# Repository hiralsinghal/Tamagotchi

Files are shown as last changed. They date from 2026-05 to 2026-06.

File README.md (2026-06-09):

# Tamagotchi

This is a Tamagotchi. It is a small handheld video game in which you have a pet. You can play with it, feed it and more depending on your firmware code.

## Features

- Play with the pet!
- Feed it!
- Make it sleep!

You can always customise the firmware to make it do what you want!

## Schematic

Here's the schematic for the Tamagotchi. It has XIAO-ESP32-C3-SMD as its MCU. It has an OLED display, a buzzer, 4 switches and a battery cell.

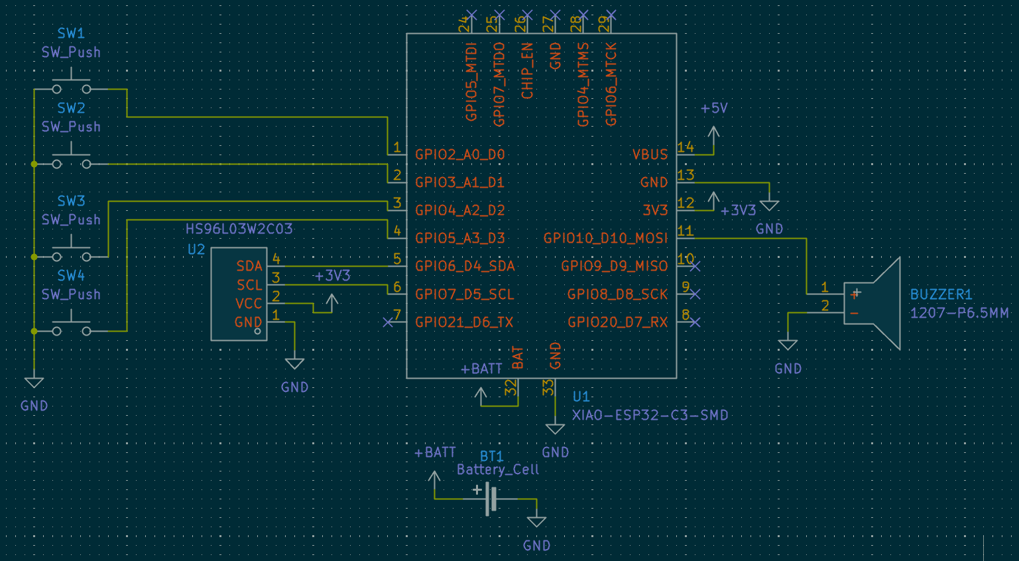
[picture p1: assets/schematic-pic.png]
Schematic


## PCB

Its a pentagon shaped PCB, which has stars on it silkscreen.

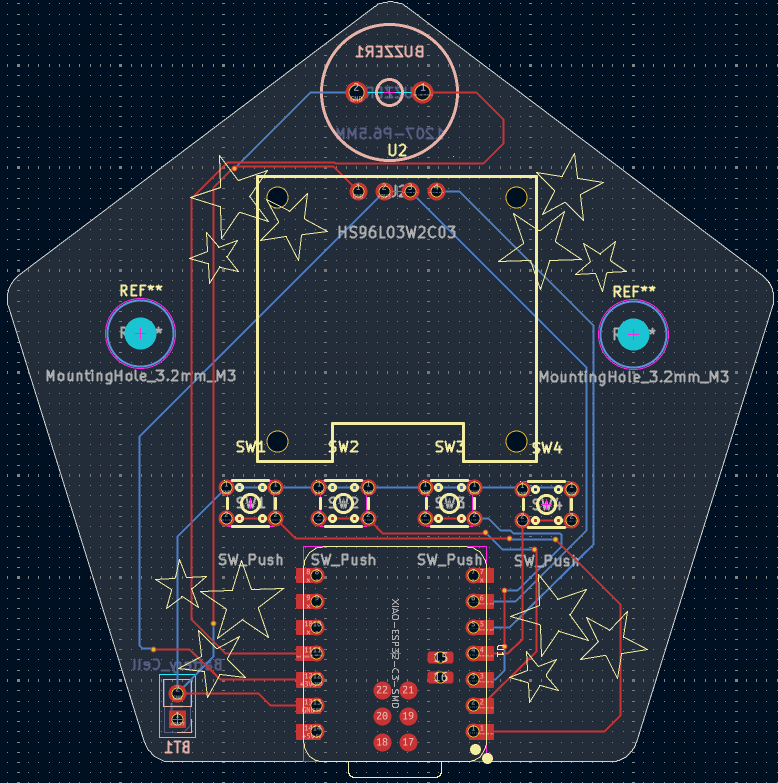
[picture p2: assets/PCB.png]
PCB


## Case

I made the case using Fusion. It has stars on the top case (goes with the PCB).

The source file is in the folder CAD.

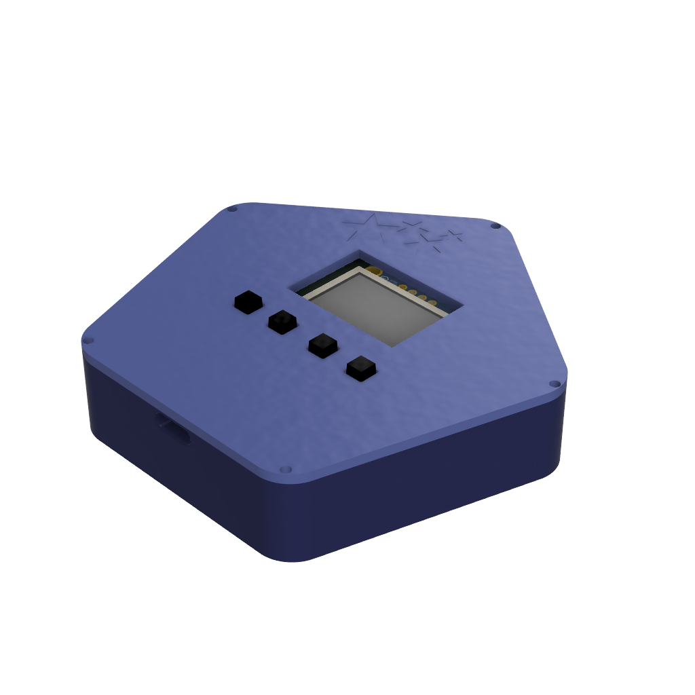
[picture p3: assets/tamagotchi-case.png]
Tamagotchi Case


## BOM

Here you can find the [BOM](BOM.csv)!

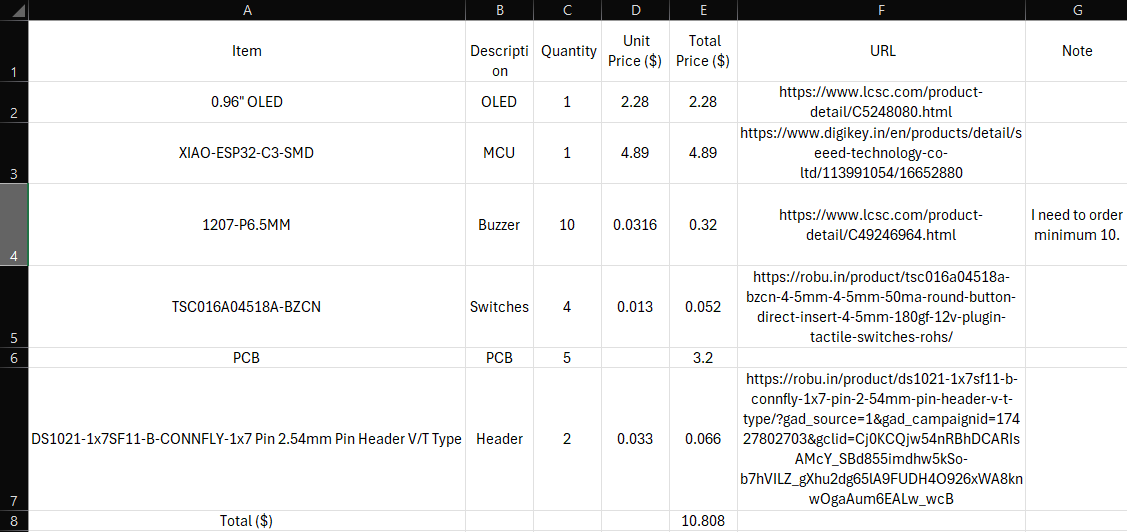
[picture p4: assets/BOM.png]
BOM


## Zine

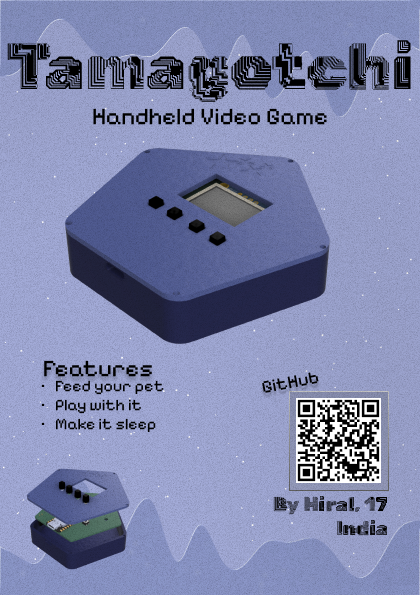
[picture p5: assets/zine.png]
Zine


## Why did I make it?

I made it for Fallout. Making this improved my electronics skills. I now know that I should read datasheets to understand how a pin on a component works. Because of this, I had to work on CAD which are now a lot better than before.

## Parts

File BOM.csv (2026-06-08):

Item | Description | Quantity | Unit Price ($) | Total Price ($) | URL | Note
0.96" OLED | OLED | 1 | 2.28 | 2.28 | https://www.lcsc.com/product-detail/C5248080.html
XIAO-ESP32-C3-SMD | MCU | 1 | 4.89 | 4.89 | https://www.digikey.in/en/products/detail/seeed-technology-co-ltd/113991054/16652880
1207-P6.5MM | Buzzer | 10 | 0.0316 | 0.32 | https://www.lcsc.com/product-detail/C49246964.html | I need to order minimum 10.
TSC016A04518A-BZCN | Switches | 4 | 0.013 | 0.052 | https://robu.in/product/tsc016a04518a-bzcn-4-5mm-4-5mm-50ma-round-button-direct-insert-4-5mm-180gf-12v-plugin-tactile-switches-rohs/
PCB | PCB | 5 |  | 3.2
DS1021-1x7SF11-B-CONNFLY-1x7 Pin 2.54mm Pin Header V/T Type | Header | 2 | 0.033 | 0.066 | https://robu.in/product/ds1021-1x7sf11-b-connfly-1x7-pin-2-54mm-pin-header-v-t-type/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
Total ($) |  |  |  | 10.808

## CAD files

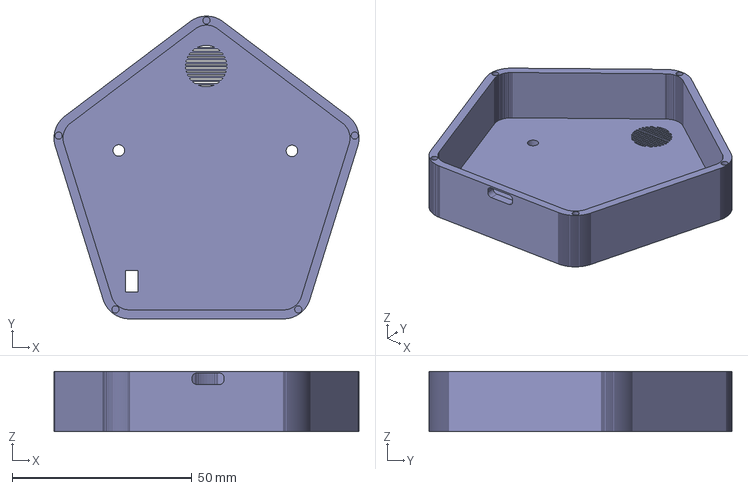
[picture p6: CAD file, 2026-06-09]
CAD/tamagotchi-bottom-case.step
84.8 x 84.1 x 16.8 mm

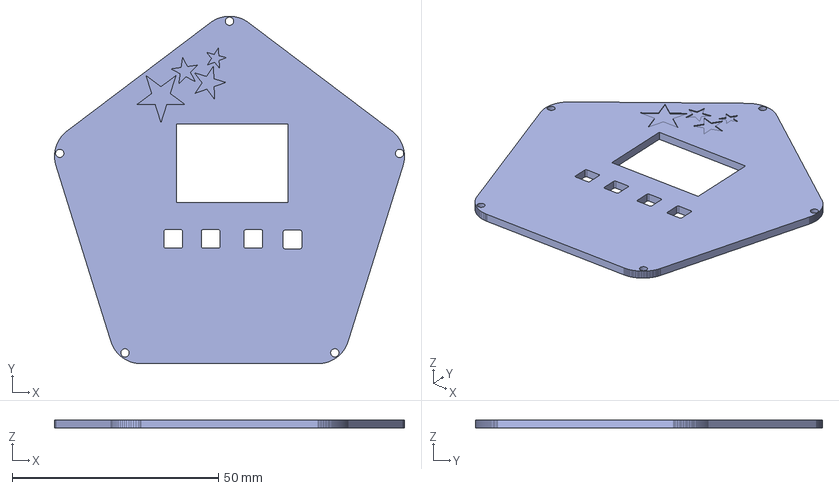
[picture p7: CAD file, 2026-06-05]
CAD/tamagotchi-top-case.step
84.8 x 84.1 x 2.00 mm

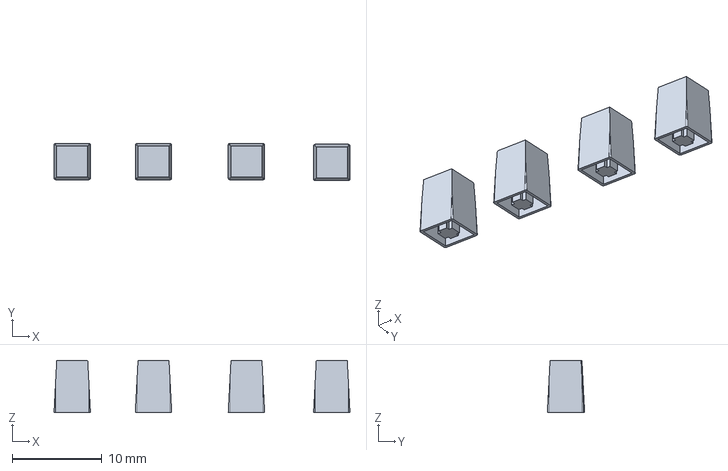
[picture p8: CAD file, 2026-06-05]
Production/tamagotchi-keycaps.step
33.0 x 4.16 x 5.80 mm

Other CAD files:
CAD/tamagotchi-case.f3z

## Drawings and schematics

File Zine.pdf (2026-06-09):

# aai

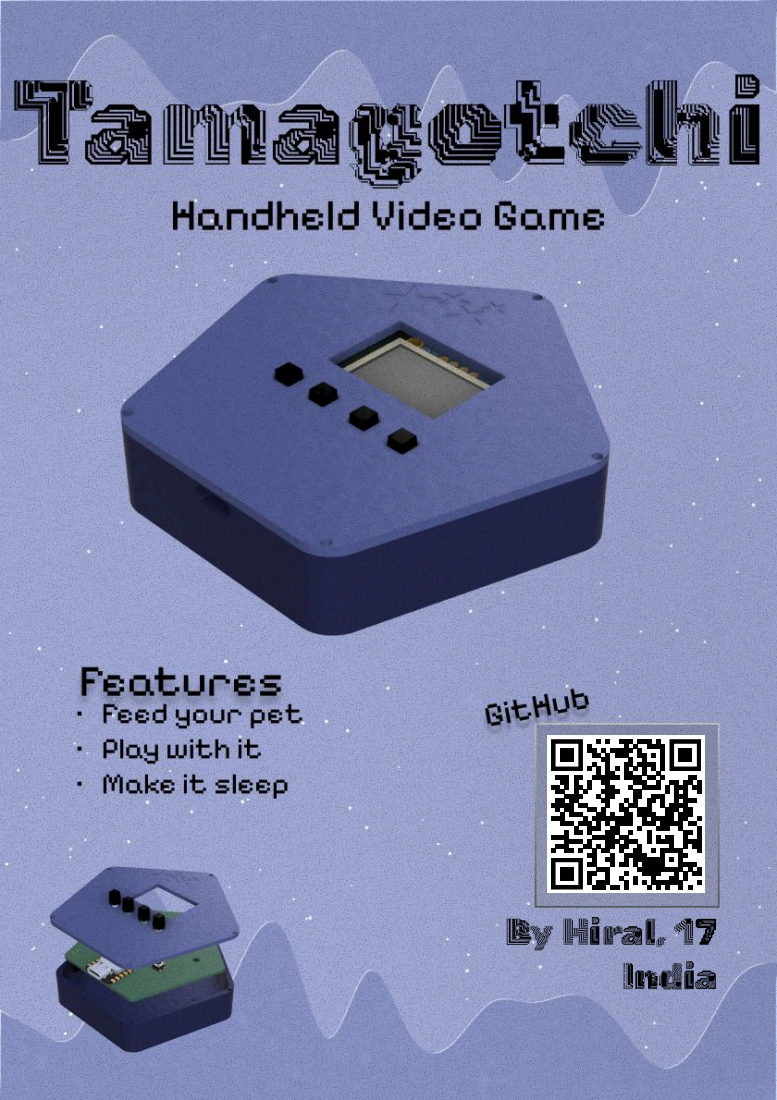
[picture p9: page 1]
By Hiral, 17 India

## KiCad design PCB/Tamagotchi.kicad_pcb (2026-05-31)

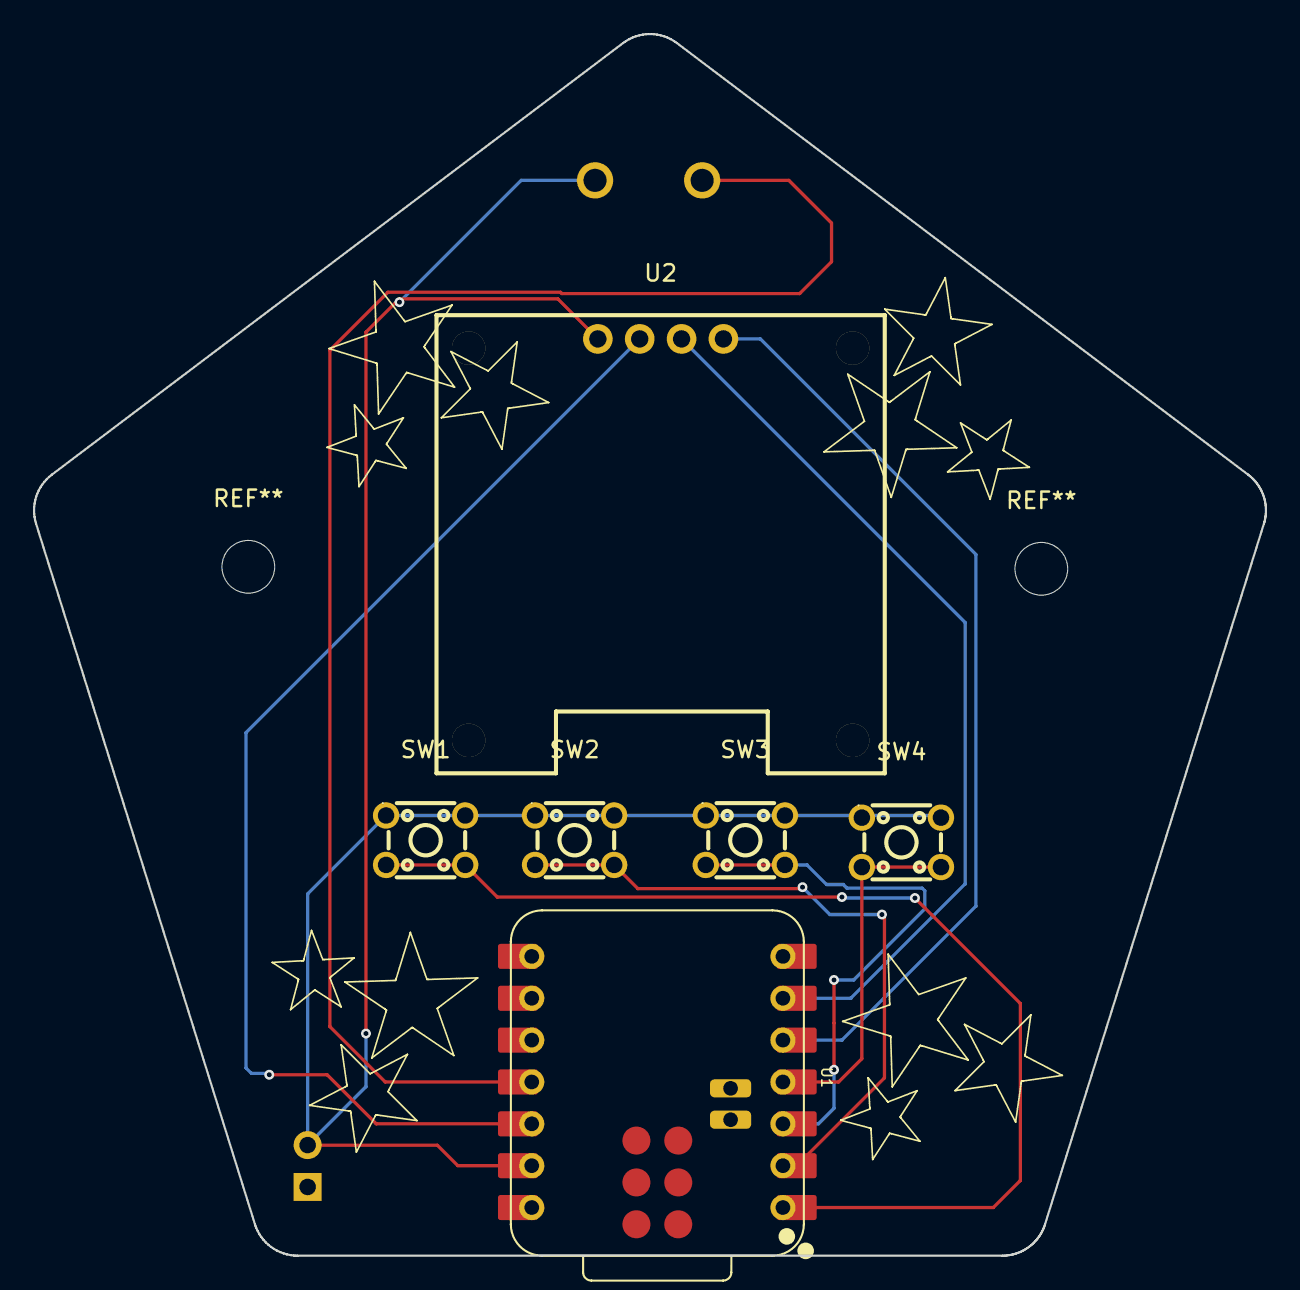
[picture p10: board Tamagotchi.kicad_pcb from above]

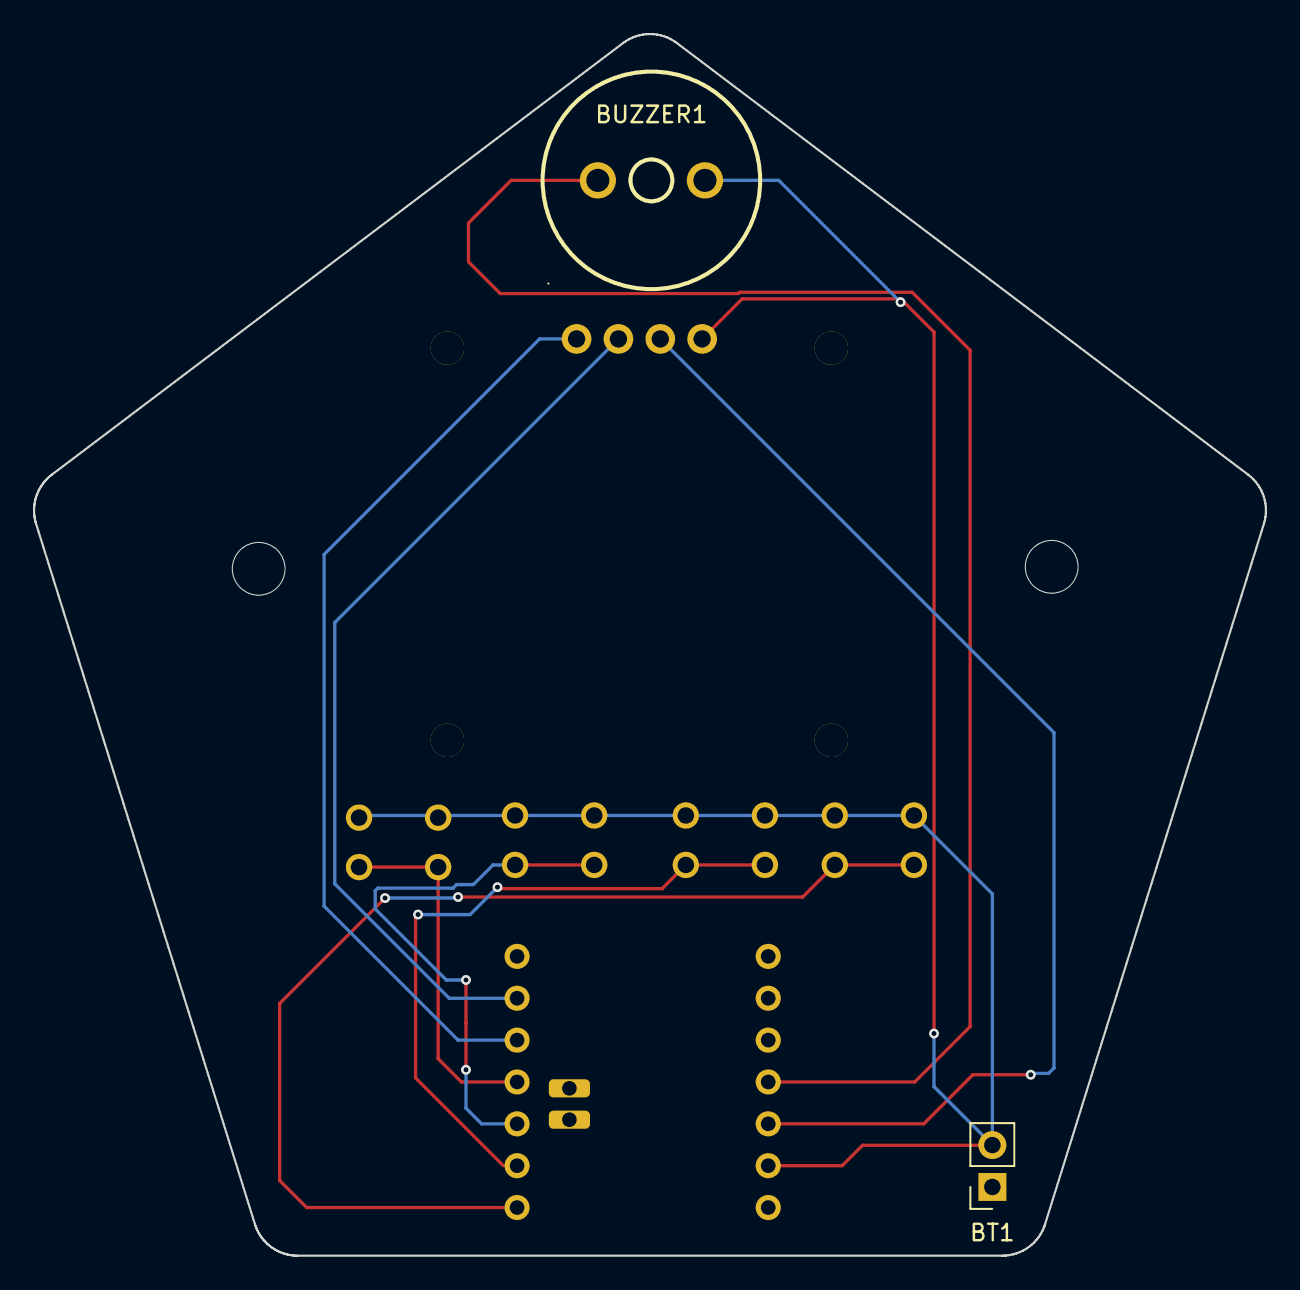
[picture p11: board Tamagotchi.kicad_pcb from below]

Board: 2 copper layers, 74.8 x 74.1 mm, 8 parts (2 on the bottom side), 9 nets.

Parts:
BT1: Battery_Cell; PinSocket_1x02_P2.54mm_Vertical
BUZZER1: 1207-P6.5MM; BUZ-TH_BD12.5-P6.50-D1.4
SW1, SW2, SW3, SW4: SW_Push; SW-TH_4P-L4.5-W4.5-P3.00-LS4.8
U1: XIAO-ESP32-C3-SMD; XIAO-ESP32-C3-DIP-SMD
U2: HS96L03W2C03; OLED-TH_L27.8-W27.2-P2.54_C9900033791

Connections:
+3V3: U1.12 (3V3), U2.2 (VCC)
GND: BT1.2 (-), BUZZER1.2 (-), SW1.1, SW2.1, SW3.1, SW4.1, U1.13 (GND), U2.1 (GND)
unnamed: BUZZER1.1 (+), U1.11 (GPIO10_D10_MOSI)
unnamed: SW1.2, U1.1 (GPIO2_A0_D0)
unnamed: SW2.2, U1.2 (GPIO3_A1_D1)
unnamed: SW3.2, U1.3 (GPIO4_A2_D2)
unnamed: SW4.2, U1.4 (GPIO5_A3_D3)
unnamed: U1.5 (GPIO6_D4_SDA), U2.4 (SDA)
unnamed: U1.6 (GPIO7_D5_SCL), U2.3 (SCL)

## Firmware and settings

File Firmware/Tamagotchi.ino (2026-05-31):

#include <Wire.h>
#include <Adafruit_GFX.h>
#include <Adafruit_SSD1306.h>

#define SCREEN_WIDTH 128
#define SCREEN_HEIGHT 64
#define OLED_RESET -1

Adafruit_SSD1306 display(SCREEN_WIDTH, SCREEN_HEIGHT, & Wire, OLED_RESET);

#define BTN1 2
#define BTN2 3
#define BTN3 4
#define BTN4 5

#define BTN_LEFT D0
#define BTN_MIDDLE_LEFT D1
#define BTN_MIDDLE_RIGHT D2
#define BTN_RIGHT D3

#define SDA_PIN 6
#define SCL_PIN 7

#define BUZZER 10

#define BUZZER_PIN D10

struct Pet {
  int hunger;
  int happiness;
  int energy;
  unsigned long age;
};

Pet pet;

enum Screen {
  SCREEN_MAIN,
  SCREEN_FEED,
  SCREEN_PLAY,
  SCREEN_SLEEP
};

Screen currentScreen = SCREEN_MAIN;

void handleScreenLogic() {
  switch(currentScreen) {

    case SCREEN_FEED:
      pet.hunger += 10;
      if(pet.hunger > 100) pet.hunger = 100;
      currentScreen = SCREEN_MAIN;
      break;

    case SCREEN_PLAY:
      pet.happiness += 10;
      pet.energy -= 5;
      if (pet.happiness > 100) pet.happiness = 100;
      if (pet.energy < 0) pet.energy = 0;
      currentScreen = SCREEN_MAIN;
      break;
    
    case SCREEN_SLEEP:
      pet.energy += 15;
      if (pet.energy > 100) pet.energy = 100;
      currentScreen = SCREEN_MAIN;
      break;

    case SCREEN_MAIN:
      break;
  }
}

unsigned long lastUpdate = 0;

void updatePet() {
  if (millis() - lastUpdate > 5000) {
    pet.hunger--;
    pet.happiness--;
    pet.energy--;

    if (pet.hunger < 0) pet.hunger = 0;
    if (pet.happiness < 0) pet.happiness =0;
    if (pet.energy < 0) pet.energy = 0;

    pet.age += 5;
    lastUpdate = millis();
  }
}

unsigned long lastButtonPress = 0;

void checkButtons() {
  if (millis() - lastButtonPress < 200) return;

  if (digitalRead(BTN_LEFT) == LOW) {
    currentScreen = SCREEN_FEED;
    tone(BUZZER_PIN, 1000, 50);
    lastButtonPress = millis();
  }

  else if (digitalRead(BTN_RIGHT) == LOW) {
    currentScreen = SCREEN_SLEEP;
    tone(BUZZER_PIN, 800, 50);
    lastButtonPress = millis();
  }
}

// Happy Face 
const unsigned char PROGMEM petHappy[] = {
  0b00000000, 0b00000000,
  0b00001111, 0b11111000,
  0b00001100, 0b00011000,
  0b00001000, 0b00001000,
  0b00001011, 0b01101000,
  0b00001000, 0b00001000,
  0b00001010, 0b00101000,
  0b00001011, 0b11101000,
  0b00001000, 0b00001000,
  0b00001111, 0b11111000,
  0b00000010, 0b00100000,
  0b00001110, 0b00111000,
  0b00001000, 0b00001000,
  0b00001000, 0b00001000,
  0b00001000, 0b00001000,
  0b00001000, 0b00001000
};

// Sad Face
const unsigned char PROGMEM petSad[] = {
  0b00000000, 0b00000000,
  0b00001111, 0b11111000,
  0b00001100, 0b00011000,
  0b00001000, 0b00001000,
  0b00001011, 0b01101000,
  0b00001000, 0b00001000,
  0b00001011, 0b11101000,
  0b00001010, 0b00101000,
  0b00001000, 0b00001000,
  0b00001111, 0b11111000,
  0b00000010, 0b00100000,
  0b00001110, 0b00111000,
  0b00001000, 0b00001000,
  0b00001000, 0b00001000,
  0b00001000, 0b00001000,
  0b00001000, 0b00001000
};

// Usage:
// display.drawBitmap(x, y, sprite, 16, 16, SSD1306_WHITE);

// Neutral Face
const unsigned char PROGMEM petNeutral[] = {
  0b00000000, 0b00000000,
  0b00001111, 0b11111000,
  0b00001100, 0b00011000,
  0b00001000, 0b00001000,
  0b00001011, 0b01101000,
  0b00001000, 0b00001000,
  0b00001000, 0b00001000,
  0b00001011, 0b11101000,
  0b00001000, 0b00001000,
  0b00001111, 0b11111000,
  0b00000010, 0b00100000,
  0b00001110, 0b00111000,
  0b00001000, 0b00001000,
  0b00001000, 0b00001000,
  0b00001000, 0b00001000,
  0b00001000, 0b00001000
};

// Sleeping Face
const unsigned char PROGMEM petSleep[] = {
  0b00000000, 0b00000000,
  0b00001111, 0b11111000,
  0b00001100, 0b00011000,
  0b00001000, 0b00001000,
  0b00001010, 0b00101000,
  0b00001000, 0b00001000,
  0b00001000, 0b00001000,
  0b00001011, 0b11101000,
  0b00001000, 0b00001000,
  0b00001111, 0b11111000,
  0b00000010, 0b00100000,
  0b00001110, 0b00111000,
  0b00001000, 0b00001000,
  0b00001000, 0b00001000,
  0b00001000, 0b00001000,
  0b00001000, 0b00001000
};

// Usage:
// display.drawBitmap(x, y, sprite, 16, 16, SSD1306_WHITE);

void render() {
  display.clearDisplay();

  const unsigned char* sprite;
  if (pet.hunger < 30 || pet.happiness < 30 || pet.energy < 30) {
    sprite = petSad;
  } else if (pet.hunger > 50 && pet.happiness > 50 && pet.energy > 50) {
    sprite = petHappy;
  } else {
    sprite = petNeutral;
  }

  display.drawBitmap(56, 2, sprite, 16, 16, SSD1306_WHITE);

  display.setTextSize(1);

  display.setCursor(0, 24);
  display.print("HUN ");
  drawBar(24, 24, pet.hunger);

  display.setCursor(0, 34);
  display.print("HAP ");
  drawBar(24, 34, pet.happiness);

  display.setCursor(0, 44);
  display.print("ENG ");
  drawBar(24, 44, pet.energy);

  display.setCursor(0, 56);
  display.println("[Feed] [Play] [Sleep]");

  display.display();
}

void drawBar(int x, int y, int value) {
  int barWidth = 100;
  int barHeight = 6;
  int fillWidth = map(value, 0, 100, 0, barWidth);

  display.drawRect(x, y, barWidth, barHeight, SSD1306_WHITE);
  display.fillRect(x, y, fillWidth, barHeight, SSD1306_WHITE);
}

void setup() {
  pinModer(BTN_LEFT, INPUT_PULLUP);
  pinMode(BTN_MIDDLE_LEFT, INPUT_PULLUP);
  pinMode(BTN_MIDDLE_RIGHT, INPUT_PULLUP);
  pinMode(BTN_RIGHT, INPUT_PULLUP);

  display.begin(SSD1306_SWITCHCAPVCC, 0x3C);
  display.clearDisplay();
  display.setTextSize(1);
  display.setTextColor(SSD1306_WHITE);
  display.setCursor(0, 0);
  display.println("Tamagotchi Init...");
  display.display();
  delay(1000);

  pet.hunger = 80;
  pet.happiness = 80;
  pet.energy = 80;
  pet.age = 0;
}

void loop() {
 checkButtons();
 updatePet();
 handleScreenLogic();
 render();
 delay(100);

}

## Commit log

2026-05-31 PCB folder done
    [Tamagotchi.kicad_pcb, Tamagotchi.kicad_sch]
2026-05-31 production & firmware
    [tamagotchi-bottom-case.step, tamagotchi-top-case.step]
2026-06-05 CAD new files
    [tamagotchi-bottom-case.step, tamagotchi-case.f3z, tamagotchi-keycaps.step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]
2026-06-05 new cad files for production
    [tamagotchi-bottom-case.step, tamagotchi-keycaps.step, tamagotchi-top-case.step]
2026-06-05 new case pic
2026-06-05 update bom
    [BOM.csv]
2026-06-05 bom update
    [BOM.csv]
2026-06-08 updated bom
    [BOM.csv]
2026-06-08 pls work
    [BOM.csv]
2026-06-09 new cad files
    [tamagotchi-bottom-case.step, tamagotchi-case.f3z]
2026-06-09 update case pic
2026-06-09 Update image reference for Tamagotchi case
2026-06-09 file changed in production
    [tamagotchi-bottom-case.step]
